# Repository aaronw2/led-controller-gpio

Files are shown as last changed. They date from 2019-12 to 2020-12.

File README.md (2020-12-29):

Daughter board for Wrover32 LED Controller

This daughter board is designed to augment the Wrover32 LED controller
board by adding additional GPIO I/O support in addition to an
accelerometer and the ability to switch the fan on and off.  Two status
LEDs are also present, one for 3.3V power and the other for when the
fan is enabled.

The I2C termination can be enabled or disabled by SW1.

SW1-1: SCL pull-up enable
SW1-2: SDA pull-up enable
SW1-3: Interrupt pull-up enable

GPIO is controlled by a PCA9575HF and the accelerometer is a MXC4005XC

I2C Addresses:
PCA9575HF: 0x20
MXC4005XC: 0x15
ADS1110A0IDBVR: 1001000 0x48

U1: NXP PCA9575HF,118
U2: Memsic MXC4005XC
U3: Texas Instruments ADS1110A0IDBVR
SW1: Würth Elektronik 416131160803
C1-C7, C9, C14: 1uF X7R 0603 (1608) capacitor
C8,C11,C13,C15: 0.1uF X7R 0603 (1608) capacitor
C10: 0.22uF XC7R 0603 (1608) capacitor
C12: 10uF X7R 0603 (1608) capacitor
D1: Toshiba CCSA15S30,L3F (protection)
D2: Würth Elektronik Red LED 150060RS75000
D3: Würth Elektronik Green LED 150060GS55040
Q1: Infineon BSS214NW
R1, R3: 4.7K 0603 (1608)
R2: 3.9K 0603 (1608)
RN1: 4.7K, 4x0603 convex, Bourns CAY16-4701F4LF

All components are available from Digikey.

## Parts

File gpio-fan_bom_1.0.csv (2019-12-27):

Component | Description | Part | References | Value | Footprint | Quantity Per PCB | Datasheet | SPURL | MPN | MFR | SPN | SPR
1 | Unpolarized capacitor | C | C1 C2 C3 C4 C5 C6 C7 C8 | 1uF | C_0603_1608Metric | 8 | ~
2 | Schottky diode | D_Schottky | D1 | D_Schottky | D_0603_1608Metric | 1 | https://toshiba.semicon-storage.com/info/docget.jsp?did=13923&prodName=CCS15S30 | https://www.digikey.com/products/en/discrete-semiconductor-products/diodes-rectifiers-single/280?k=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 | CCS15S30,L3F | Toshiba Semiconductor and Storage | CCS15S30L3FCT-ND | Digikey
3 | Generic connector, single row, 01x02, script generated (kicad-library-utils/schlib/autogen/connector/) | Conn_01x02 | J3 J6 | Conn_01x02 | PinSocket_1x02_P1.27mm_Vertical | 2 | ~ | https://www.digikey.com/product-detail/en/samtec-inc/SLM-102-01-S-S/SAM9931-ND/6678668 | SLM-102-01-S-S | Samtec Inc. | SAM9931-ND | Digikey
4 | Generic connector, single row, 01x02, script generated (kicad-library-utils/schlib/autogen/connector/) | Conn_01x02 | J7 | Conn_01x02 | PinHeader_1x02_P1.27mm_Vertical | 1 | ~
5 | Generic connector, single row, 01x02, script generated (kicad-library-utils/schlib/autogen/connector/) | Conn_01x02 | J8 | Conn_01x02 | PinHeader_1x02_P2.54mm_Vertical | 1 | ~
6 | Generic connector, single row, 01x03, script generated (kicad-library-utils/schlib/autogen/connector/) | Conn_01x03 | J5 | Conn_01x03 | Molex_KK-254_AE-6410-03A_1x03_P2.54mm_Vertical | 1 | ~
7 | Generic connector, single row, 01x05, script generated (kicad-library-utils/schlib/autogen/connector/) | Conn_01x05 | J1 | Conn_01x05 | PinSocket_1x05_P1.27mm_Vertical | 1 | http://suddendocs.samtec.com/prints/slm-s.pdf | https://www.digikey.com/product-detail/en/samtec-inc/SLM-105-01-L-S/SAM11788-ND/6691859 | SLM-105-01-L-S | Samtec Inc. | SAM11788-ND | Digikey
8 | Generic connector, single row, 01x05, script generated (kicad-library-utils/schlib/autogen/connector/) | Conn_01x05 | J2 | Conn_01x05 | PinHeader_1x05_P2.54mm_Vertical | 1 | ~
9 | Generic connector, double row, 02x07, odd/even pin numbering scheme (row 1 odd numbers, row 2 even numbers), script generated (kicad-library-utils/schlib/autogen/connector/) | Conn_02x07_Odd_Even | J4 | Conn_02x07_Odd_Even | PinHeader_2x07_P2.54mm_Horizontal | 1 | ~
10 | 20V Vds, 1.5A Id, N-Channel MOSFET, SOT-323 | BSS214NW | Q1 | BSS214NW | SOT-323_SC-70 | 1 | https://www.infineon.com/dgdl/Infineon-BSS214NW-DS-v02_02-en.pdf?fileId=db3a30431b3e89eb011b695aebc01bde | https://www.digikey.com/products/en/discrete-semiconductor-products/transistors-fets-mosfets-single/278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 | BSS214NWH6327XTSA1 | Infineon Technologies | BSS214NWH6327XTSA1CT-ND | Digikey
11 | 4 resistor network, parallel topology, DIP package | R_Pack04 | RN1 | 4.7K | R_Array_Convex_4x0603 | 1 | ~
12 | 3x DIP Switch, Single Pole Single Throw (SPST) switch, small symbol | SW_DIP_x03 | SW1 | SW_DIP_x03 | SW_DIP_SPSTx03_Slide_Wurth_416131160803_8.89x4.98mm_W2.65mm_P1.27mm | 1 | https://katalog.we-online.de/em/datasheet/4161311608xx.pdf | https://www.digikey.com/products/en/switches/dip-switches/194?k=416131160803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 | 416131160803 | Würth Elektronik | 732-3853-1-ND | Digikey
13 | Three-Axiss Accelerometer | MXC400XXC | U2 | MXC400XXC | MXC400XXC | 1 | http://www.memsic.cn/userfiles/files/Datasheets/Accelerometer-Datasheets/MXC400xXC_Rev_B.pdf
14 | 16-bit I2C-bus and SMBus, level translating, low voltage GPIO with reset and interrupt | PCA9575HF | U1 | PCA9575HF | HWQFN-24_EP_4x4_Pitch0.5mm | 1 | https://www.nxp.com/docs/en/data-sheet/PCA9575.pdf | https://www.digikey.com/products/en/integrated-circuits-ics/interface-i-o-expanders/749?k=PCA9575HF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 | PCA9575HF,118 | NXP USA Inc. | 568-4771-1-ND | Digikey
Component Groups: | 14
Component Count: | 22
Fitted Components: | 22
Number of PCBs: | 1
Total components: | 22
Schematic Version: | 1
Schematic Date: | 2019-11-30
PCB Variant: | default
BoM Date: | Tue 10 Dec 2019 07:33:33 PM PST
Schematic Source: | /home/aaronw/kicad/Projects/Ralph/led-controller-wrover32/gpio-fan/gpio-fan.sch
KiCad Version: | Eeschema 5.1.5-5.1.5

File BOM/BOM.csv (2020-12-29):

Refs | Value | Footprint | Quantity | DESC | MFR | MPN | SPR | SPN | SPURL
SW1 | SW_DIP_x03 | Aaron:SW_DIP_SPSTx03_Slide_Wurth_416131160803_8.89x4.98mm_W2.65mm_P1.27mm | 1 | - | Würth Elektronik | 416131160803 | Digikey | 732-3853-1-ND | https://www.digikey.com/products/en/switches/dip-switches/194?k=416131160803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
C8;C11;C13;C15 | 0.1uF | Capacitor_SMD:C_0603_1608Metric | 4 | - | Samsung | CL10B105KA8NNNC | Digikey | 1276-1184-1-ND | -
C10 | 0.22uF | Capacitor_SMD:C_0603_1608Metric | 1 | - | Samsung | CL10B105KA8NNNC | Digikey | 1276-1184-1-ND | -
C12 | 10uF | Capacitor_SMD:C_0603_1608Metric | 1 | - | Samsung | CL10B105KA8NNNC | Digikey | 1276-1184-1-ND | -
C1;C3;C4;C5;C6;C2;C7;C9;C14 | 1uF | Capacitor_SMD:C_0603_1608Metric | 9 | - | Samsung | CL10B105KA8NNNC | Digikey | 1276-1184-1-ND | -
J4 | Conn_02x07_Odd_Even | Connector_PinHeader_2.54mm:PinHeader_2x07_P2.54mm_Horizontal | 1 | - | Adam Tech | BHR-14-HUA-ML | Digikey | 2057-BHR-14-HUA-ML-ND | https://www.digikey.com/product-detail/en/adam-tech/BHR-14-HUA-ML/2057-BHR-14-HUA-ML-ND/9832592
J3;J6 | Conn_01x02 | Connector_PinSocket_1.27mm:PinSocket_1x02_P1.27mm_Vertical | 2 | - | Samtec Inc. | SLM-102-01-S-S | Digikey | SAM9931-ND | https://www.digikey.com/products/en?mpart=SLM-102-01-S-S&v=612
J1 | Conn_01x05 | Connector_PinSocket_1.27mm:PinSocket_1x05_P1.27mm_Vertical | 1 | - | Samtec Inc. | SLM-105-01-L-S | Digikey | SAM11788-ND | https://www.digikey.com/product-detail/en/samtec-inc/SLM-105-01-L-S/SAM11788-ND/6691859
D1 | D_Schottky | Diode_SMD:D_0603_1608Metric | 1 | - | Toshiba Semiconductor and Storage | CCS15S30,L3F | Digikey | CCS15S30L3FCT-ND | https://www.digikey.com/products/en/discrete-semiconductor-products/diodes-rectifiers-single/280?k=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
D3 | LED GREEN | LED_SMD:LED_0603_1608Metric | 1 | - | Würth Elektronik | 150060GS55040 | Digikey | 732-12014-1-ND | https://www.digikey.com/products/en/optoelectronics/led-indication-discrete/105?k=150060gs55040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
D2 | LED RED | LED_SMD:LED_0603_1608Metric | 1 | - | Würth Elektronik | 150060RS75000 | Digikey | 732-4978-1-ND | https://www.digikey.com/products/en/optoelectronics/led-indication-discrete/105?k=150060RS75000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
U1 | PCA9575HF | Package_DFN_QFN:Texas_S-PVQFN-N24_EP2.1x2.1mm | 1 | - | NXP USA Inc. | PCA9575HF,118 | Digikey | 568-4771-1-ND | https://www.digikey.com/products/en/integrated-circuits-ics/interface-i-o-expanders/749?k=PCA9575HF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
U2 | LSM303AGRTR | Package_LGA:LGA-12_2x2mm_P0.5mm | 1 | Ultra-compact high-performance eCompass module: ultra-low-power 3D accelerometer and 3D magnetometer | STMicroelectronics | LSM303AGR | Mouser | 511-LSM303AGRTR | https://www.mouser.com/ProductDetail/STMicroelectronics/LSM303AGRTR
U3 | ADS1110 | Package_TO_SOT_SMD:SOT-23-6 | 1 | IC ADC 16BIT SIGMA-DELTA SOT23-6 | Texas Instruments | ADS1110A0IDBVR | Digikey | 296-25890-1-ND | https://www.digikey.com/en/products/detail/texas-instruments/ADS1110A0IDBVR/1689057
Q1 | BSS214NW | Package_TO_SOT_SMD:SOT-323_SC-70 | 1 | - | Infineon Technologies | BSS214NWH6327XTSA1 | Digikey | BSS214NWH6327XTSA1CT-ND | https://www.digikey.com/products/en/discrete-semiconductor-products/transistors-fets-mosfets-single/278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
R2 | 3.9K | Resistor_SMD:R_0603_1608Metric | 1 | 3.9 kOhms ±1% 0.1W, 1/10W Chip Resistor 0603 (1608 Metric) Moisture Resistant Thick Film | Bourns Inc. | CR0603-FX-3901ELF | Digikey | CR0603-FX-3901ELFCT-ND | https://www.digikey.com/en/products/detail/bourns-inc/CR0603-FX-3901ELF/3783997
R3;R1 | 4.7K | Resistor_SMD:R_0603_1608Metric | 2 | RES SMD 1K OHM 1% 1/10W 0603 | Yageo | RC0603FR-071KL | Digikey | 311-1.00KHRCT-ND | https://www.digikey.com/product-detail/en/yageo/RC0603FR-071KL/311-1.00KHRCT-ND/729790
RN1 | 4.7K | Resistor_SMD:R_Array_Convex_4x0603 | 1 | - | Bourns Inc. | CAY16-4701F4LF | Digikey | CAY16-4701F4LFCT-ND | -

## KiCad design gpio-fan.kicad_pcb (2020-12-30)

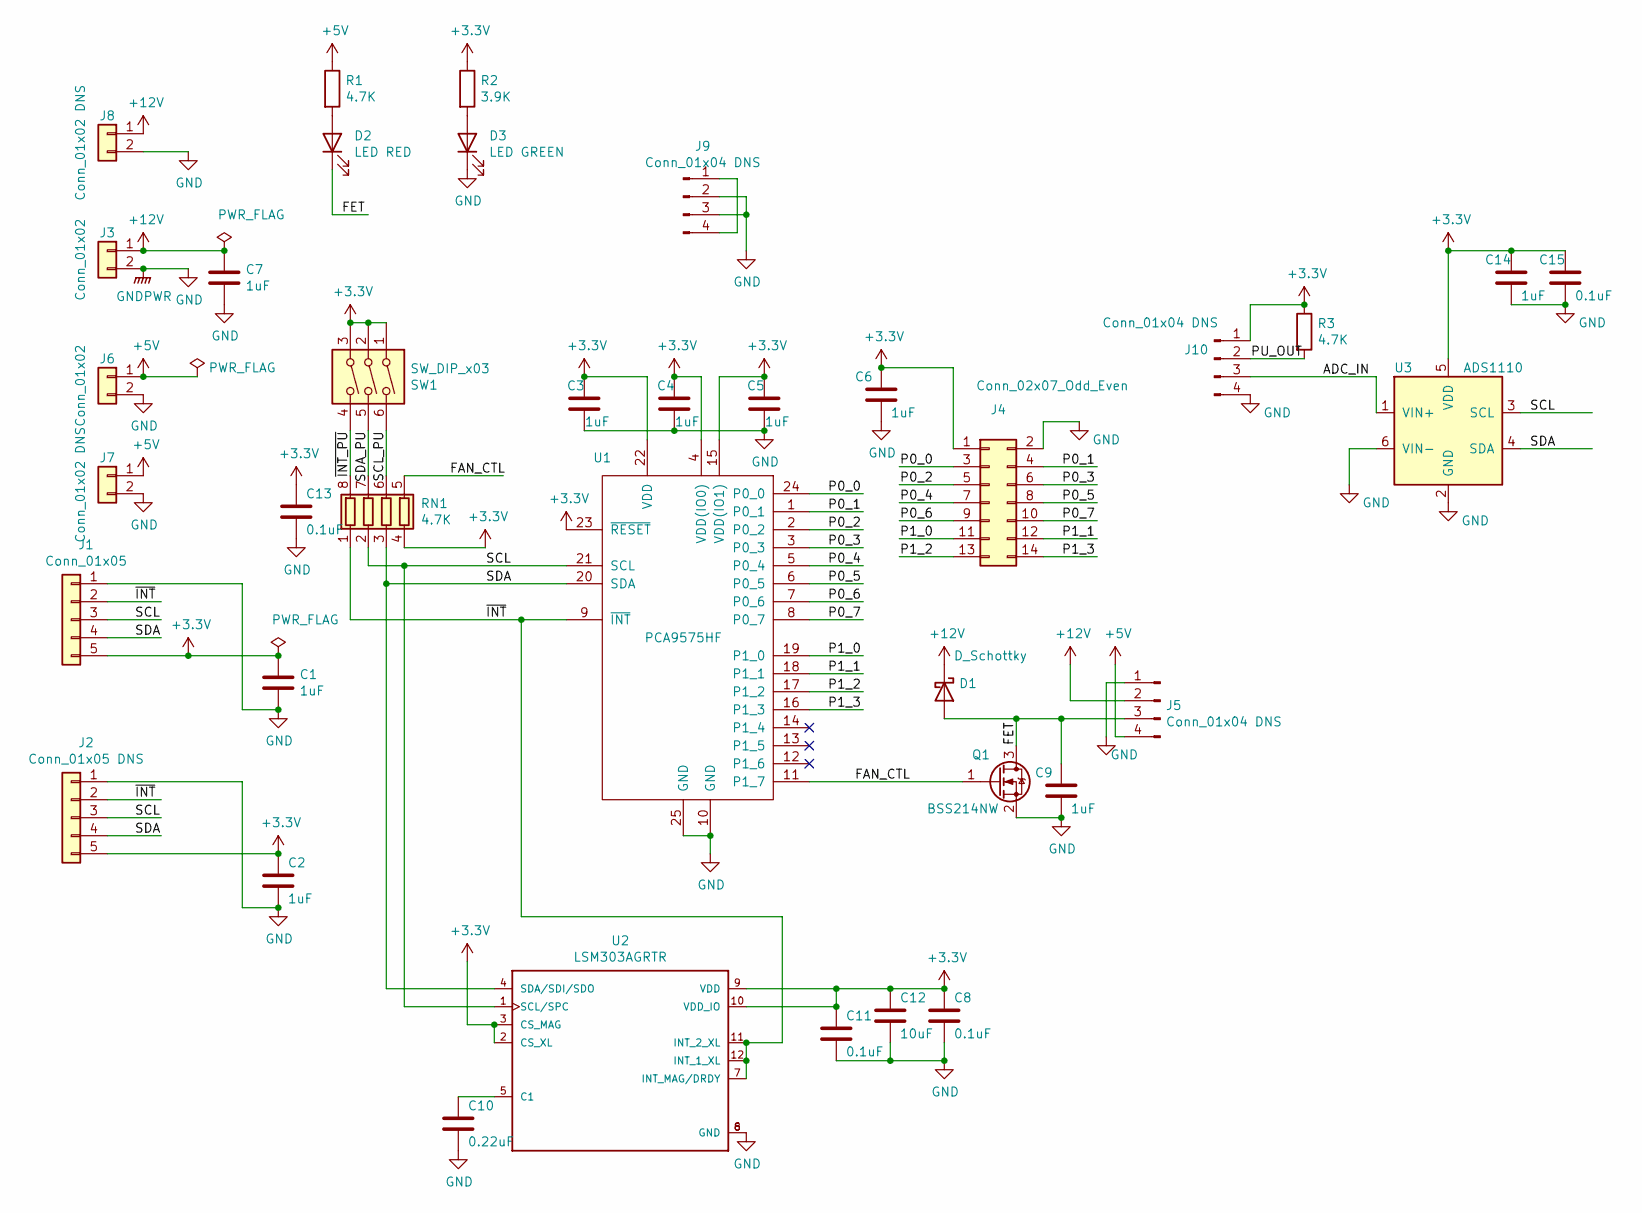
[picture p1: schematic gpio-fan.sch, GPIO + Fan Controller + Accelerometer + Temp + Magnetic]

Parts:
C1, C2, C3, C4, C5, C6, C7, C9, C14: 1uF; C_0603_1608Metric; MPN CL10B105KA8NNNC
C8, C11, C13, C15: 0.1uF; C_0603_1608Metric; MPN CL10B105KA8NNNC
C10: 0.22uF; C_0603_1608Metric; MPN CL10B105KA8NNNC
C12: 10uF; C_0603_1608Metric; MPN CL10B105KA8NNNC
D1: D_Schottky; D_0603_1608Metric; MPN CCS15S30,L3F
D2: LED RED; LED_0603_1608Metric; MPN 150060RS75000
D3: LED GREEN; LED_0603_1608Metric; MPN 150060GS55040
J1: Conn_01x05; PinSocket_1x05_P1.27mm_Vertical; MPN SLM-105-01-L-S
J2: Conn_01x05 DNS; PinHeader_1x05_P2.54mm_Vertical
J3, J6: Conn_01x02; PinSocket_1x02_P1.27mm_Vertical; MPN SLM-102-01-S-S
J4: Conn_02x07_Odd_Even; PinHeader_2x07_P2.54mm_Horizontal; MPN BHR-14-HUA-ML
J5: Conn_01x04 DNS; PinHeader_1x04_P2.54mm_Vertical; MPN 1719710104
J7: Conn_01x02 DNS; PinHeader_1x02_P1.27mm_Vertical
J8: Conn_01x02 DNS; PinHeader_1x02_P2.54mm_Vertical
J9: Conn_01x04 DNS; PinHeader_1x04_P2.54mm_Vertical
J10: Conn_01x04 DNS; PinHeader_1x04_P1.27mm_Vertical
Q1: BSS214NW; SOT-323_SC-70; MPN BSS214NWH6327XTSA1
R1, R3: 4.7K; R_0603_1608Metric; MPN RC0603FR-071KL
R2: 3.9K; R_0603_1608Metric; MPN CR0603-FX-3901ELF
RN1: 4.7K; R_Array_Convex_4x0603; MPN CAY16-4701F4LF
SW1: SW_DIP_x03; SW_DIP_SPSTx03_Slide_Wurth_416131160803_8.89x4.98mm_W2.65mm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; MPN 416131160803
U1: PCA9575HF; Texas_S-PVQFN-N24_EP2.1x2.1mm; MPN PCA9575HF,118
U2: LSM303AGRTR; LGA-12_2x2mm_P0.5mm; MPN LSM303AGR
U3: ADS1110; SOT-23-6; MPN ADS1110A0IDBVR

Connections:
+5V: J5.4, J6.1, J7.1, R1.1
+12V: C7.1, D1.1 (K), J3.1, J5.2, J8.1
/ADC_IN: J10.3, U3.1 (VIN+)
/FAN_CTL: Q1.1 (G), RN1.5 (R4.2), U1.11 (P1_7)
/FET: C9.1, D1.2 (A), D2.1 (K), J5.3, Q1.3 (D)
/P0_0: J4.3, U1.24 (P0_0)
/P0_1: J4.4, U1.1 (P0_1)
/P0_2: J4.5, U1.2 (P0_2)
/P0_3: J4.6, U1.3 (P0_3)
/P0_4: J4.7, U1.5 (P0_4)
/P0_5: J4.8, U1.6 (P0_5)
/P0_6: J4.9, U1.7 (P0_6)
/P0_7: J4.10, U1.8 (P0_7)
/P1_0: J4.11, U1.19 (P1_0)
/P1_1: J4.12, U1.18 (P1_1)
/P1_2: J4.13, U1.17 (P1_2)
/P1_3: J4.14, U1.16 (P1_3)
/PU_OUT: J10.2, R3.2
/SCL: J1.3, J2.3, RN1.2 (R2.1), U1.21 (SCL), U2.1 (SCL/SPC), U3.3 (SCL)
/SCL_PU: RN1.6 (R3.2), SW1.6
/SDA: J1.4, J2.4, RN1.3 (R3.1), U1.20 (SDA), U2.4 (SDA/SDI/SDO), U3.4 (SDA)
/SDA_PU: RN1.7 (R2.2), SW1.5
/~INT: J1.2, J2.2, RN1.1 (R1.1), U1.9 (~INT), U2.7 (INT_MAG/DRDY), U2.11 (INT_2_XL), U2.12 (INT_1_XL)
/~INT_PU: RN1.8 (R1.2), SW1.4
GND: C1.2, C2.2, C3.2, C4.2, C5.2, C6.2, C7.2, C8.2, C9.2, C10.2, C11.2, C12.2, C13.2, C14.2, C15.2, D3.1 (K), J1.1, J2.1, J3.2, J4.2, J5.1, J6.2, J7.2, J8.2, J9.2, J9.3, J10.4, Q1.2 (S), U1.10 (GND), U1.25 (GND), U2.6 (GND), U2.8 (GND), U3.2 (GND), U3.6 (VIN-); also elsewhere on the board
unnamed: D2.2 (A), R1.2
unnamed: D3.2 (A), R2.2
unnamed: J9.1, J9.4

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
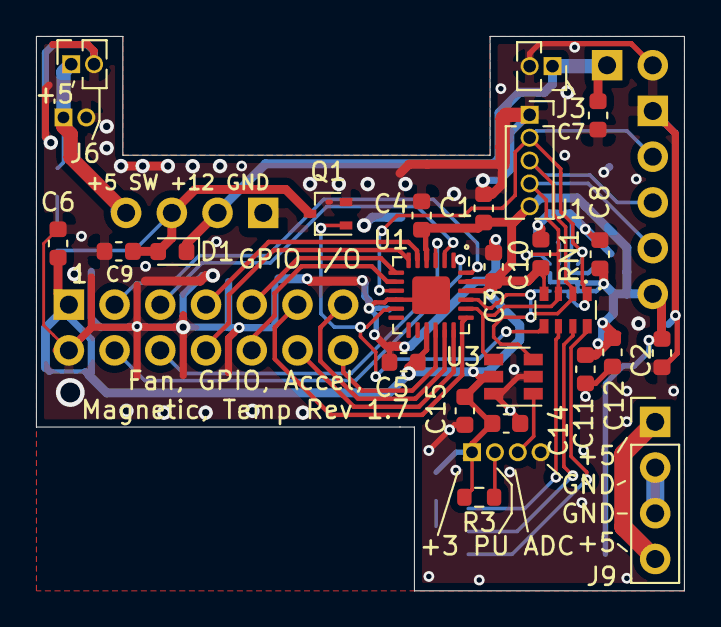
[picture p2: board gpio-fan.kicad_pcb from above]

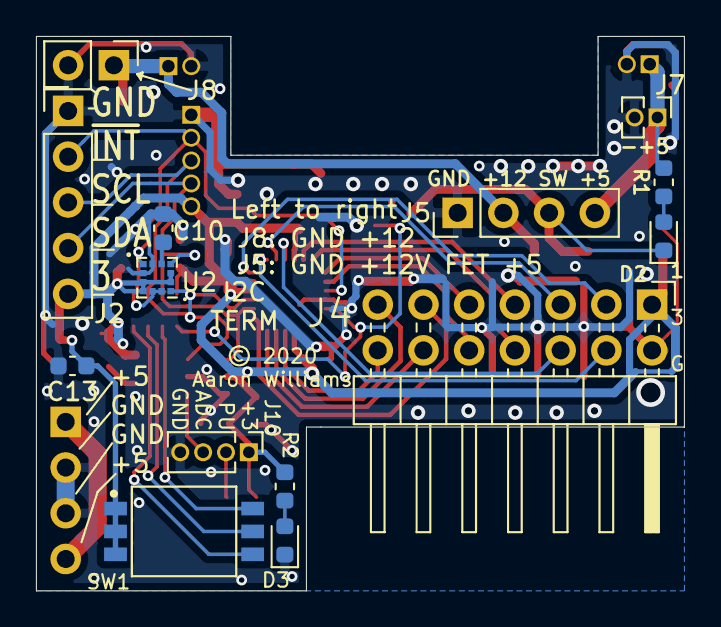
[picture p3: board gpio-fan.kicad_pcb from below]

Board: 2 copper layers, 36.0 x 30.8 mm, 38 parts (14 on the bottom side), 30 nets.

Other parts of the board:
C10#2: 0.22uF; C_0603_1608Metric

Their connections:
GND: C10#2.2; also elsewhere on the board

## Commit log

2019-12-27 Initial checkin v1.0
    [BOM.csv, gpio-fan.kicad_pcb, gpio-fan.sch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]
2020-04-21 Added large via to match 3.8, minor changes
    [BOM.csv, gpio-fan.kicad_pcb, gpio-fan.sch]
2020-04-26 Upgraded to revision 1.3, changed temperature sensor and accelerometer.
    This now uses a combined part that should be a lot easier to solder.
    The new ST part also includes a temperature sensor and it is supported
    by the Arduino library.
    [BOM.csv, gpio-fan.kicad_pcb, gpio-fan.sch]
2020-07-02 Fixed mislabeled capacitor and other minor changes.
    [BOM.csv, gpio-fan.kicad_pcb, gpio-fan.sch]
2020-12-29 Fixed J6, dimmed LEDs, and added ADC for light sensor
    This also expands the board size where the switches are so that it can be
    better mounted to the main board via the +5V pins near the speaker connector.
    [BOM.csv, gpio-fan.kicad_pcb, gpio-fan.sch]
2020-12-30 Made minimum via hole size 0.3mm. Bump to 1.7 due to layout changes.
    [gpio-fan.kicad_pcb]

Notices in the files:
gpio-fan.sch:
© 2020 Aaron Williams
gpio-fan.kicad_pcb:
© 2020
